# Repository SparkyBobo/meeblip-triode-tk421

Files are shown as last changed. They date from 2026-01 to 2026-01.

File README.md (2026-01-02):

# That Time I Promised My Friend a Synth… and Finally Delivered (40 Years Later!)

Let’s rewind to the 1980s—big hair, neon everything, and me, a seventh grader with a wild electronics obsession. Enter my buddy “F” (not his real name, but let’s roll with it—think F Murray Abraham from Amadeus,

because inside jokes are forever). F was the piano prodigy, I was the kid who thought soldering irons were cool, and together we were the ultimate middle school odd couple.

One day, I had a brilliant idea: “Hey F, why don’t you give me a few hundred bucks so I can build you a Moog-style synthesizer from a magazine article?” Because that’s how open-source worked back then—no GitHub, just guts and glue.

F, being the wise soul, realized this was probably a recipe for disaster (and possibly a fire hazard). Instead, F asked for a Roland synth for Christmas. Smart move, right? That was the moment F’s musical journey truly began.

He’s now a fantastic musician, and we rocked out in our high school band, the *Residudes*. F swears my synth hype is what nudged him from classical piano to modern music, so I’ll take partial credit for his rockstar status.

Fast forward: F and I still swap music nerd tidbits. He’s even inspired me to learn music (shoutout to my 70+ day Duolingo streak!). But here’s the kicker—I never actually built that synth. Oops. So, I decided it was time to

make good on my decades-old promise. After some deep dives into my parts bin and the wilds of the internet, I found the perfect open-source project: the [MeeBlip Triode](https://meeblip.com/products/meeblip-triode-synthesizer). It’s affordable, it’s awesome, and it’s my way of finally delivering on that synth promise from the Reagan era.

So here’s to friendship, music, and never letting a 40-year-old promise die. Sometimes, the best things really are worth the wait.

## Build Notes: AKA “How I Frankensteined This Synth Together”

* Parts Bin Olympics: My main goal was to spend as little money as possible on parts, not to be cheap, just to makes this a thing I threw together as much as possible.
* Analog Chip Hunt: Turns out, my stash didn’t have the right analog chips. Had to buy those. Same story for eight matching 10k potentiometers—those got ordered, but I did have a vintage audio taper 10k for volume just chilling in the bin.
* Processor Swap: The original build called for a different processor, but I had an ATMega 644 lying around, so why not? Plus, the DIP-40 package gives it that retro “I built this in the 80s” vibe. I tried to stick to the original circuit and microprocessor connections as much as possible not because I'm afraid of firmware changes, I just thoughts it would be easier.
* Through-Hole Throwback: Most resistors and capacitors are through-hole, because that’s what I had and they look delightfully vintage. Non-electrolytic caps? All from a random kit I bought for experimenting.
* Why use 1 part when 2 will do: Some components ended up with two passives in parallel or series. Why? Because I was determined to use what I had instead of buying new stuff. If you spot C14.1, C14.2, R15.1, or R15.2 looking a little extra, that’s just me flexing my parts bin muscles.
* Surface Mount Sneak-In: A few surface mount parts made it in, mostly to save space and because I had leftovers. Sorry for the modern touch, but hey, it’s all about balance.
* PCB Front Panel Hack: I love using PCBs as front panels—Kicad makes layout a breeze and it’s cheap. This synth is rocking three boards: bottom for the guts, middle for perfect potentiometer height, and the faceplate for that pro finish.
* Oldest Part Award: The power switch is a true relic—I’ve been lugging it around since the late 80s. It's actually an ON-OFF-ON switch but I thought when else am I gonna use it? And what's so bad about having 2 on positions? Runnerup is the resistors: Straight outta my college electronics kit from the late 80s/early 90s.

## Where Credit Is Due

Let’s be real: this project is standing on the shoulders of other. I didn’t just whip up the MeeBlip Triode out of thin air—there’s a whole crew who did the heavy lifting long before I ever busted out my soldering iron. So, here’s a big, sparkly shout-out (because it’s not just what the license says, it’s the right thing to do):

MeeBlip Contributors:

* Jarek Ziembicki: The OG—created the original AVRsynth, which is the backbone of this whole project.
* Laurie Biddulph: Translation superstar! Worked with Jarek to make those comments readable in English and ported the code to Atmega16.
* Daniel Kruszyna: Idea machine—extended AVRsynth and sprinkled in several concepts that MeeBlip now rocks.
* Julian Schmidt: Filter genius—came up with the original Meeblip digital filter algorithm.
* Axel Werner: Code ninja—optimized, squashed bugs, and brought in new bandlimited waveforms.
* James Grahame: Hardware and firmware mastermind behind MeeBlip’s physical and digital awesomeness.
* [MeeBlip Triode on GitHub](https://github.com/MeeBlip/meeblip-triode)

So, if you’re loving this synth saga, send some good vibes to these legends. Without their brainpower, my 40-year-old promise would still be stuck in the parts bin!

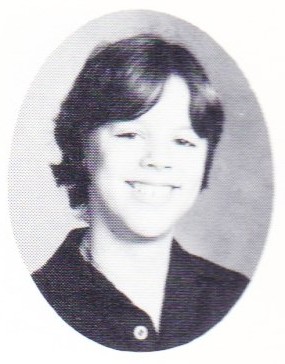
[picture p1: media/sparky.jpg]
Sparky from 1983
Sparky: 

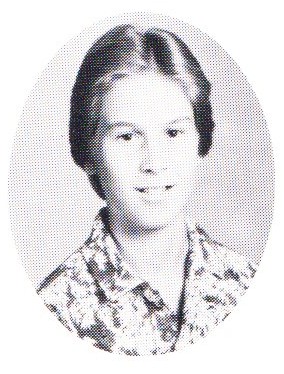
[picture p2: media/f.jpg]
F from 1983
F:

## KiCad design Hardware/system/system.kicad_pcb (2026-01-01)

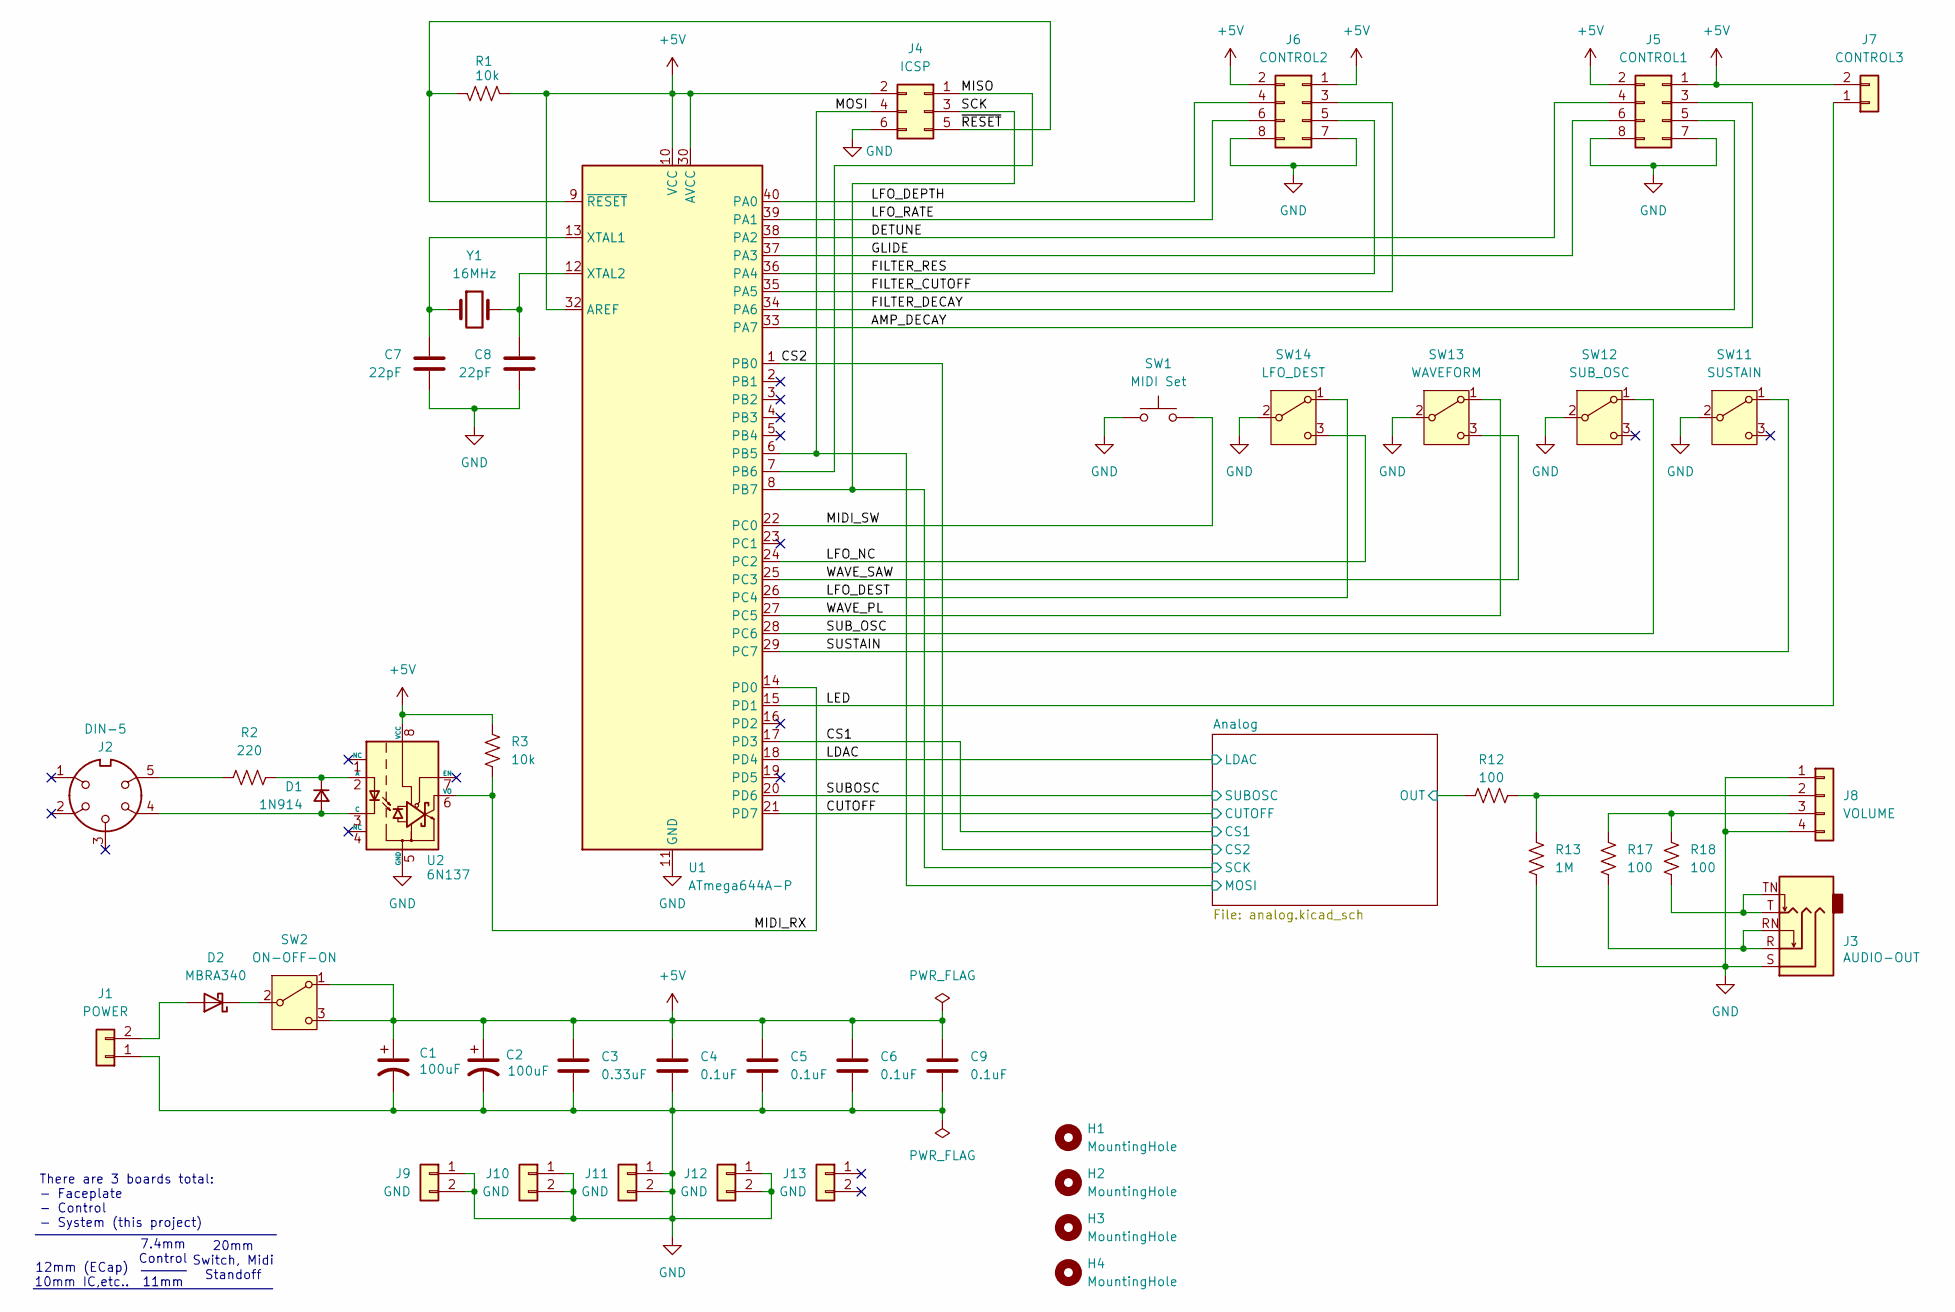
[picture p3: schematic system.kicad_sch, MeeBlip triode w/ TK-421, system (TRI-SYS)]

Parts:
C1, C2: 100uF; CP_Radial_D5.0mm_P2.00mm
C3: 0.33uF; C_Rect_L7.2mm_W3.0mm_P5.00mm_FKS2_FKP2_MKS2_MKP2
C4, C5, C6, C9: 0.1uF; C_Rect_L7.2mm_W3.0mm_P5.00mm_FKS2_FKP2_MKS2_MKP2
C7, C8: 22pF; C_Rect_L7.2mm_W3.0mm_P5.00mm_FKS2_FKP2_MKS2_MKP2
D1: 1N914; D_DO-35_SOD27_P10.16mm_Horizontal
D2: MBRA340; D_SMA_Handsoldering
H1, H2, H3, H4: MountingHole; MountingHole_3mm
J1: POWER; PhoenixContact_MC_1,5_2-G-3.81_1x02_P3.81mm_Horizontal
J2: DIN-5; MIDI_DIN_5
J3: AUDIO-OUT; Jack_3.5mm_Adafruit_1699_Horizontal
J4: ICSP; PinHeader_2x03_P2.54mm_Vertical
J5: CONTROL1; PinHeader_2x04_P2.54mm_Vertical
J6: CONTROL2; PinHeader_2x04_P2.54mm_Vertical
J7: CONTROL3; PinHeader_1x02_P2.54mm_Vertical
J8: VOLUME; PinHeader_1x04_P2.54mm_Vertical
J9, J10, J11, J12, J13: GND; PinHeader_1x02_P2.54mm_Vertical
R1: 10k; R_1206_3216Metric_Pad1.30x1.75mm_HandSolder
R2: 220; R_Axial_DIN0207_L6.3mm_D2.5mm_P10.16mm_Horizontal
R3: 10k; R_Axial_DIN0207_L6.3mm_D2.5mm_P10.16mm_Horizontal
R12, R17, R18: 100; R_Axial_DIN0207_L6.3mm_D2.5mm_P10.16mm_Horizontal
R13: 1M; R_Axial_DIN0207_L6.3mm_D2.5mm_P10.16mm_Horizontal
SW1: MIDI Set; SW_PUSH_6mm
SW2: ON-OFF-ON; ESWITCH_100_SPDT_M1_RA
SW11: SUSTAIN; ESWITCH_100_SPDT_M1
SW12: SUB_OSC; ESWITCH_100_SPDT_M1
SW13: WAVEFORM; ESWITCH_100_SPDT_M1
SW14: LFO_DEST; ESWITCH_100_SPDT_M1
U1: ATmega644A-P; DIP-40_W15.24mm
U2: 6N137; DIP-8_W7.62mm
Y1: 16MHz; Crystal_HC49-U_Vertical

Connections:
+5V: C1.1, C2.1, C3.1, C4.1, C5.1, C6.1, C9.1, J4.2, J5.1, J5.2, J6.1, J6.2, J7.2, R1.1, R3.1, SW2.1 (A), SW2.3 (C), U1.10 (VCC), U1.30 (AVCC), U1.32 (AREF), U2.8 (VCC); also elsewhere on the board
/AMP_DECAY: J5.3, U1.33 (PA7)
/Analog/OUT: R12.1; also elsewhere on the board
/CS1: U1.17 (PD3); also elsewhere on the board
/CS2: U1.1 (PB0); also elsewhere on the board
/CUTOFF: U1.21 (PD7); also elsewhere on the board
/DETUNE: J5.4, U1.38 (PA2)
/FILTER_CUTOFF: J6.3, U1.35 (PA5)
/FILTER_DECAY: J5.5, U1.34 (PA6)
/FILTER_RES: J6.5, U1.36 (PA4)
/GLIDE: J5.6, U1.37 (PA3)
/LDAC: U1.18 (PD4); also elsewhere on the board
/LED: J7.1, U1.15 (PD1)
/LFO_DEPTH: J6.4, U1.40 (PA0)
/LFO_DEST: SW14.1 (A), U1.26 (PC4)
/LFO_NC: SW14.3 (C), U1.24 (PC2)
/LFO_RATE: J6.6, U1.39 (PA1)
/MIDI_RX: R3.2, U1.14 (PD0), U2.6 (VO)
/MIDI_SW: SW1.2, U1.22 (PC0)
/MISO: J4.1, U1.7 (PB6)
/MOSI: J4.4, U1.6 (PB5); also elsewhere on the board
/SCK: J4.3, U1.8 (PB7); also elsewhere on the board
/SUBOSC: U1.20 (PD6); also elsewhere on the board
/SUB_OSC: SW12.1 (A), U1.28 (PC6)
/SUSTAIN: SW11.1 (A), U1.29 (PC7)
/WAVE_PL: SW13.1 (A), U1.27 (PC5)
/WAVE_SAW: SW13.3 (C), U1.25 (PC3)
/~RESET: J4.5, R1.2, U1.9 (~RESET)
GND: C1.2, C2.2, C3.2, C4.2, C5.2, C6.2, C7.2, C8.2, C9.2, J1.1, J3.S, J4.6, J5.7, J5.8, J6.7, J6.8, J8.1, J8.4, J9.1, J9.2, J10.1, J10.2, J11.1, J11.2, J12.1, J12.2, R13.2, SW1.1, SW11.2 (B), SW12.2 (B), SW13.2 (B), SW14.2 (B), U1.11 (GND), U1.31 (GND), U2.5 (GND); also elsewhere on the board
unnamed: D1.2 (A), J2.4, U2.3 (C)
unnamed: D1.1 (K), R2.2, U2.2 (A)
unnamed: D2.2 (A), J1.2
unnamed: D2.1 (K), SW2.2 (B)
unnamed: J2.5, R2.1
unnamed: J3.R, J3.RN, R17.2
unnamed: J3.T, J3.TN, R18.2
unnamed: J8.2, R12.2, R13.1
unnamed: J8.3, R17.1, R18.1
unnamed: C7.1, U1.13 (XTAL1), Y1.1
unnamed: C8.1, U1.12 (XTAL2), Y1.2

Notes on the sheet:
There are 3 boards total: - Faceplate - Control - System (this project)
10mm IC,etc..
20mm Switch, Midi Standoff
12mm (ECap)
11mm
7.4mm Control

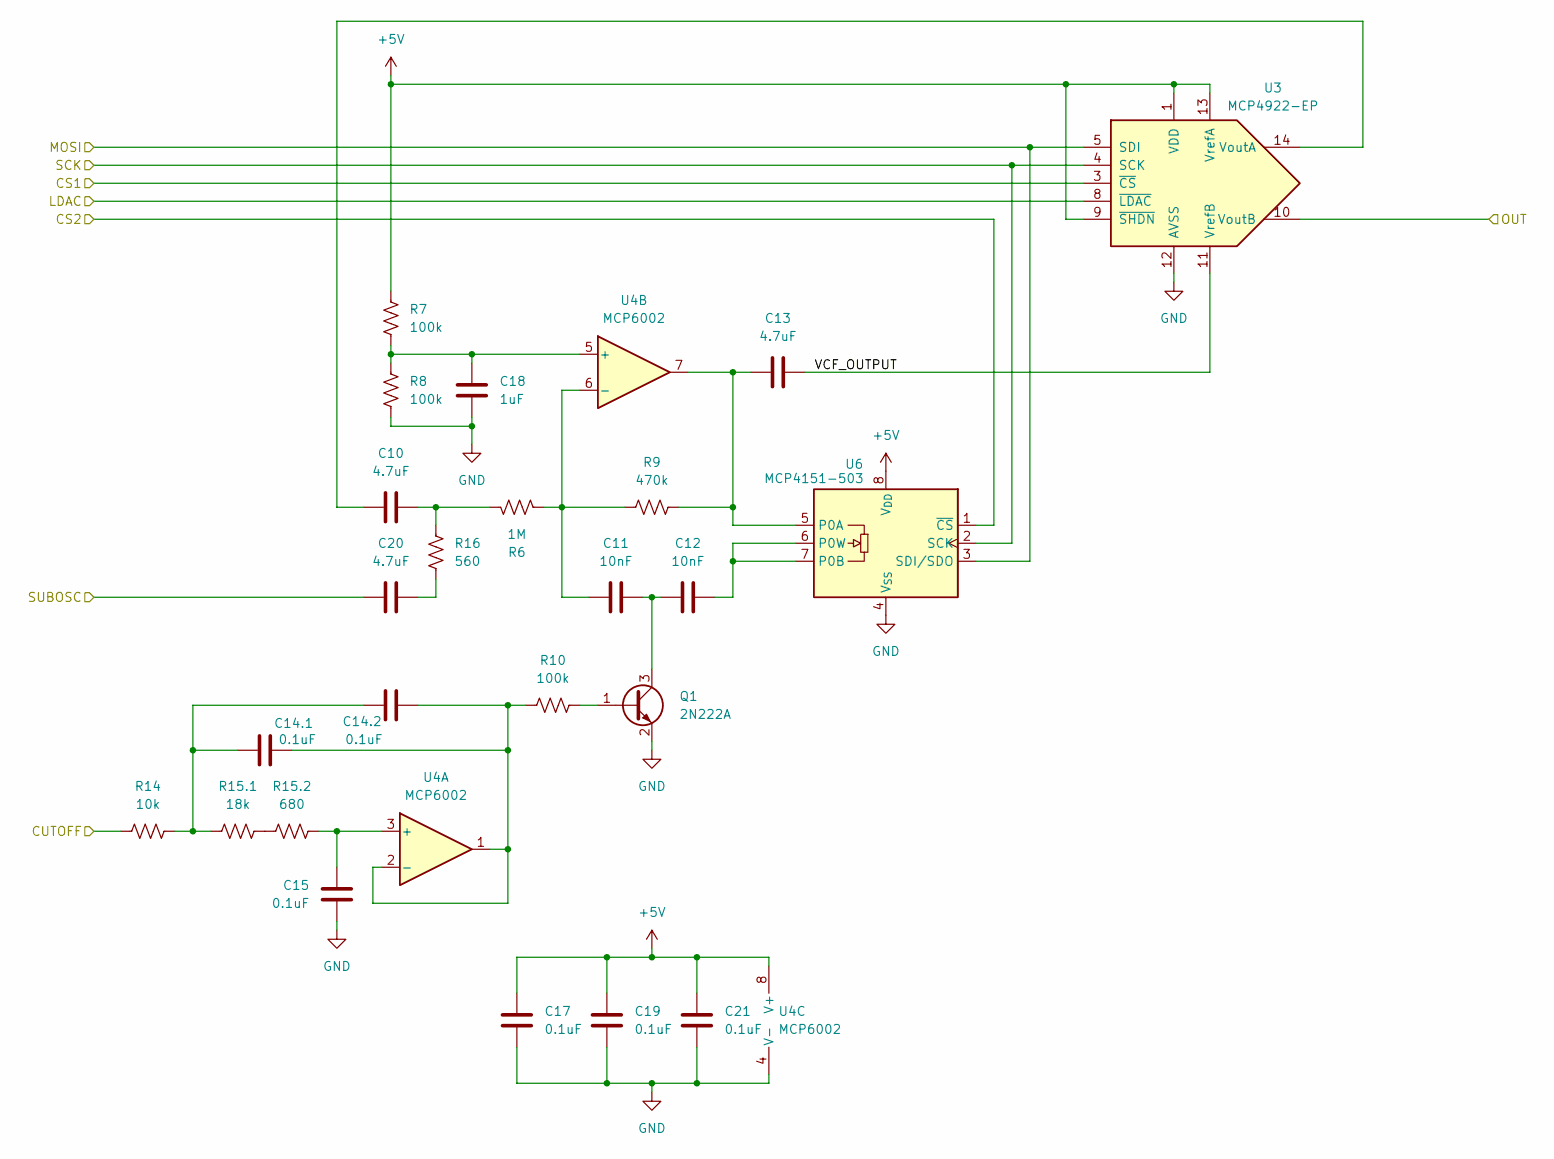
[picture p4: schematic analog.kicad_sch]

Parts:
C10, C13, C20: 4.7uF; C_Rect_L7.2mm_W3.0mm_P5.00mm_FKS2_FKP2_MKS2_MKP2
C11, C12: 10nF; C_Rect_L7.2mm_W3.0mm_P5.00mm_FKS2_FKP2_MKS2_MKP2
C14.1, C14.2, C15, C17, C19, C21: 0.1uF; C_Rect_L7.2mm_W3.0mm_P5.00mm_FKS2_FKP2_MKS2_MKP2
C18: 1uF; C_Rect_L7.2mm_W3.0mm_P5.00mm_FKS2_FKP2_MKS2_MKP2
Q1: 2N222A; TO-92_HandSolder
R6: 1M; R_Axial_DIN0207_L6.3mm_D2.5mm_P10.16mm_Horizontal
R7, R8, R10: 100k; R_Axial_DIN0207_L6.3mm_D2.5mm_P10.16mm_Horizontal
R9: 470k; R_Axial_DIN0207_L6.3mm_D2.5mm_P10.16mm_Horizontal
R14: 10k; R_Axial_DIN0207_L6.3mm_D2.5mm_P10.16mm_Horizontal
R15.1: 18k; R_Axial_DIN0207_L6.3mm_D2.5mm_P10.16mm_Horizontal
R15.2: 680; R_Axial_DIN0207_L6.3mm_D2.5mm_P10.16mm_Horizontal
R16: 560; R_Axial_DIN0207_L6.3mm_D2.5mm_P10.16mm_Horizontal
U3: MCP4922-EP; DIP-14_W7.62mm
U4: MCP6002; DIP-8_W7.62mm
U6: MCP4151-503; DIP-8_W7.62mm

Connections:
+5V: C17.1, C19.1, C21.1, R7.1, U3.1 (VDD), U3.9 (~SHDN), U3.13 (VrefA), U4.8 (V+), U6.8 (V_{DD}); also elsewhere on the board
/Analog/OUT: U3.10 (VoutB); also elsewhere on the board
/Analog/VCF_OUTPUT: C13.2, U3.11 (VrefB)
/CS1: U3.3 (~CS); also elsewhere on the board
/CS2: U6.1 (~CS); also elsewhere on the board
/CUTOFF: R14.1; also elsewhere on the board
/LDAC: U3.8 (~LDAC); also elsewhere on the board
/MOSI: U3.5 (SDI), U6.3 (SDI/SDO); also elsewhere on the board
/SCK: U3.4 (SCK), U6.2 (SCK); also elsewhere on the board
/SUBOSC: C20.1; also elsewhere on the board
GND: C15.2, C17.2, C18.2, C19.2, C21.2, Q1.2 (E), R8.2, U3.12 (AVSS), U4.4 (V-), U6.4 (V_{SS}); also elsewhere on the board
unnamed: C10.2, R6.2, R16.1
unnamed: C14.1.1, C14.2.2, R14.2, R15.1.1
unnamed: C20.2, R16.2
unnamed: Q1.1 (B), R10.2
unnamed: C11.2, C12.1, Q1.3 (C)
unnamed: R15.1.2, R15.2.1
unnamed: C10.1, U3.14 (VoutA)
unnamed: C15.1, R15.2.2, U4.3 (+)
unnamed: C14.1.2, C14.2.1, R10.1, U4.1, U4.2 (-)
unnamed: C18.1, R7.2, R8.1, U4.5 (+)
unnamed: C11.1, R6.1, R9.1, U4.6 (-)
unnamed: C13.1, R9.2, U4.7, U6.5 (P0A)
unnamed: C12.2, U6.6 (P0W), U6.7 (P0B)

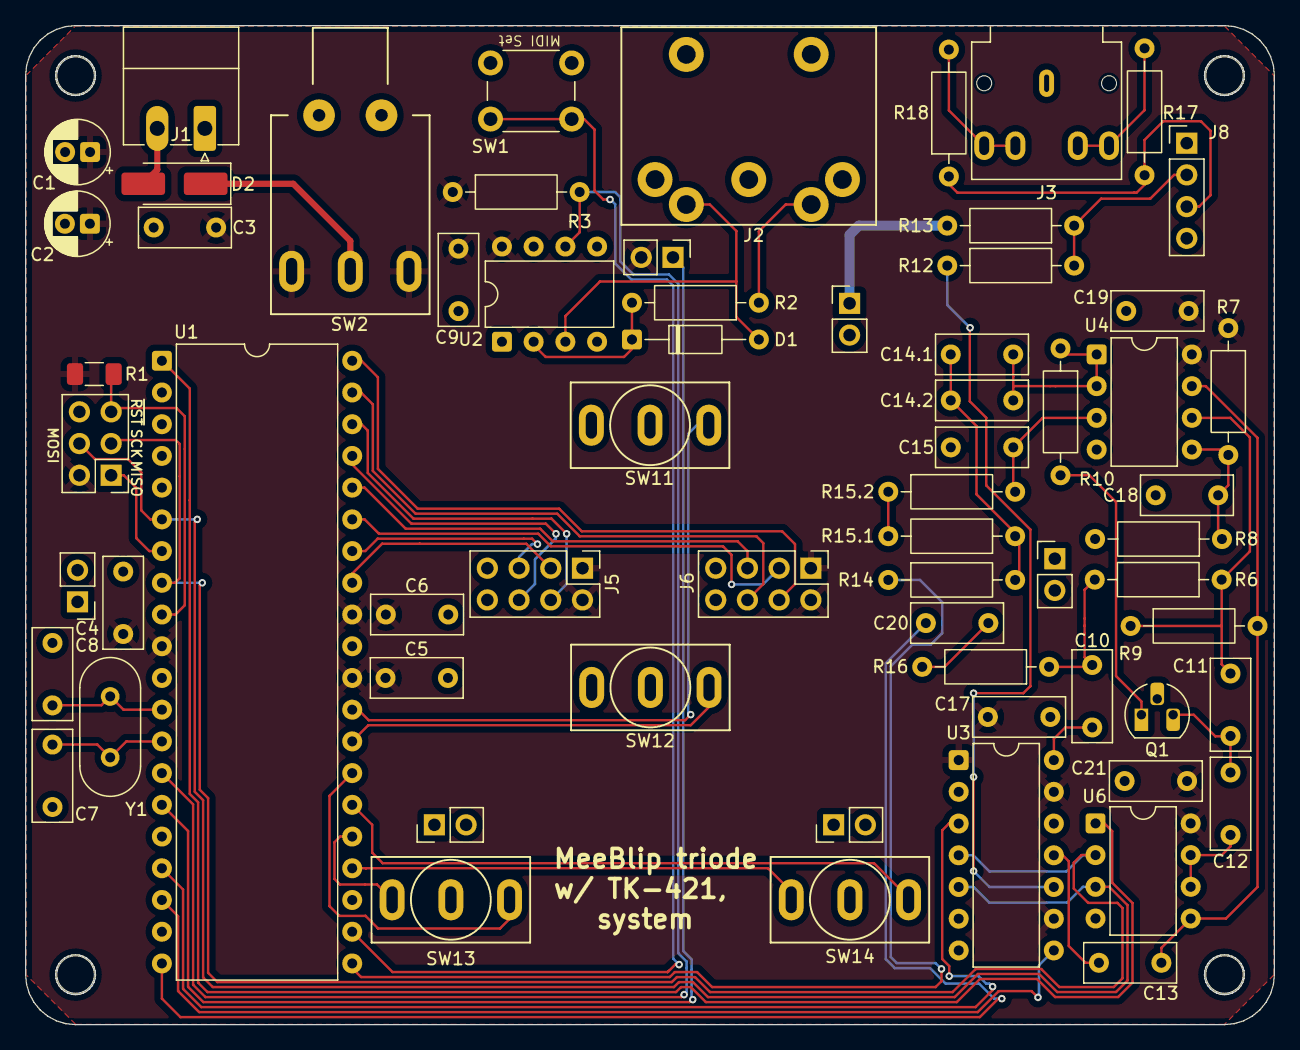
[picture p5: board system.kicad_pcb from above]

Board: 2 copper layers, 100.0 x 80.0 mm, 69 parts (0 on the bottom side), 54 nets.

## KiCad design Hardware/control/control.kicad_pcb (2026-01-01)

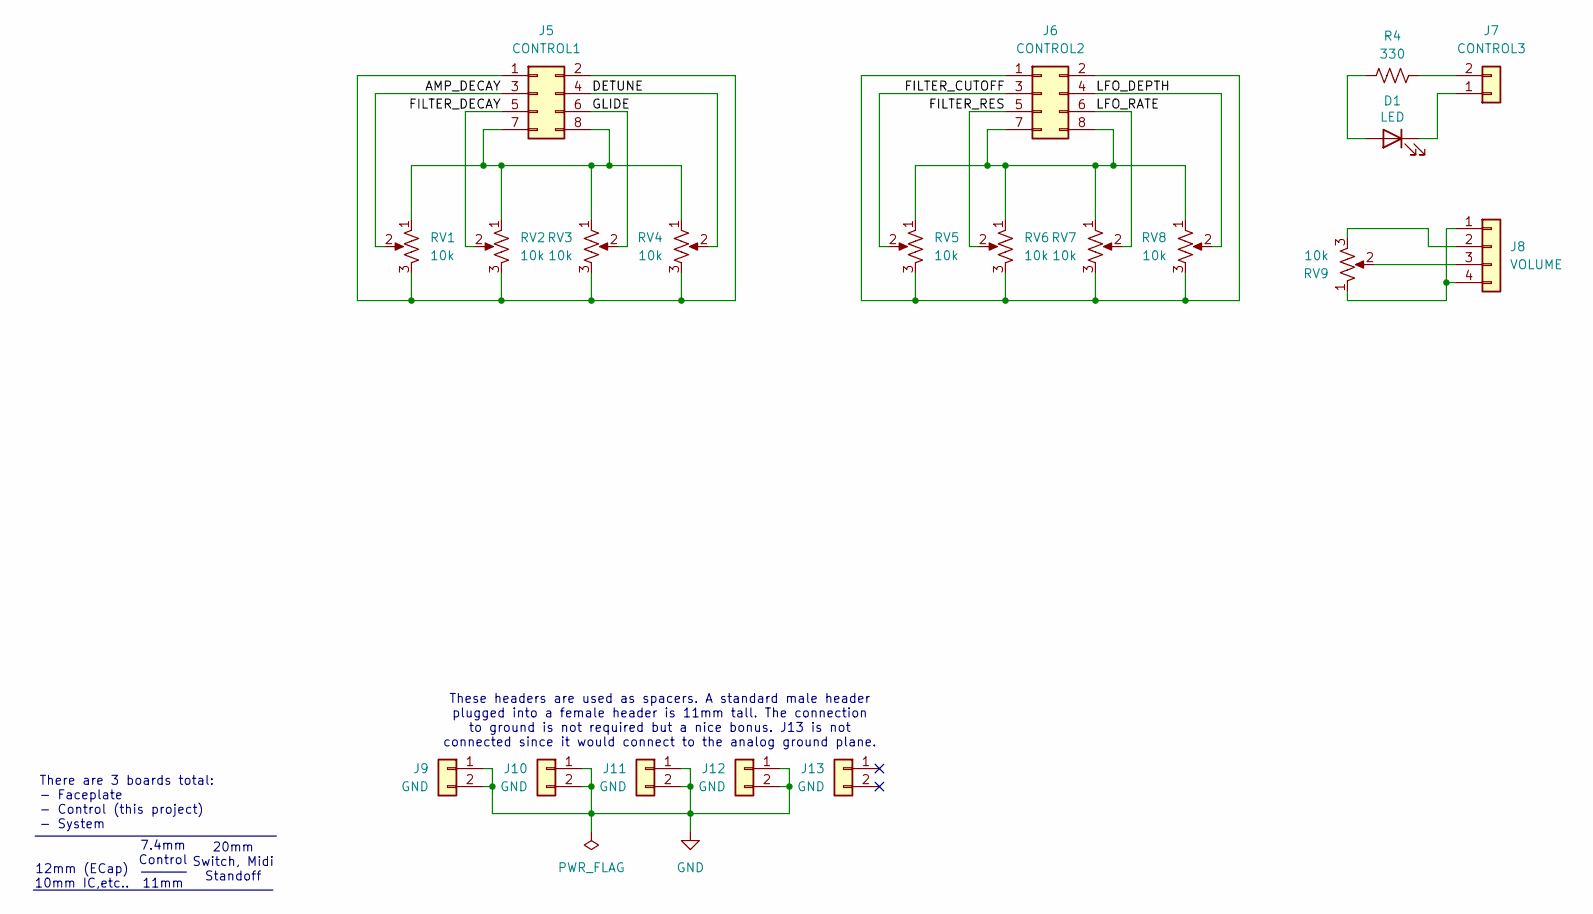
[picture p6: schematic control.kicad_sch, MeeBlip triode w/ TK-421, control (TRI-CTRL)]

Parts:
D1: LED; LED_D5.0mm
J5: CONTROL1; PinHeader_2x04_P2.54mm_Vertical
J6: CONTROL2; PinHeader_2x04_P2.54mm_Vertical
J7: CONTROL3; PinHeader_1x02_P2.54mm_Vertical
J8: VOLUME; PinHeader_1x04_P2.54mm_Vertical
J9, J10, J11, J12, J13: GND; PinHeader_1x02_P2.54mm_Vertical
R4: 330; R_Axial_DIN0207_L6.3mm_D2.5mm_P10.16mm_Horizontal
RV1, RV2, RV3, RV4, RV5, RV6, RV7, RV8, RV9: 10k; BOURNS_PTV09A_1

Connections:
/AMP_DECAY: J5.3, RV1.2
/DETUNE: J5.4, RV4.2
/FILTER_CUTOFF: J6.3, RV5.2
/FILTER_DECAY: J5.5, RV2.2
/FILTER_RES: J6.5, RV6.2
/GLIDE: J5.6, RV3.2
/LFO_DEPTH: J6.4, RV8.2
/LFO_RATE: J6.6, RV7.2
GND: J9.1, J9.2, J10.1, J10.2, J11.1, J11.2, J12.1, J12.2
unnamed: D1.2 (A), R4.1
unnamed: D1.1 (K), J7.1
unnamed: J5.1, J5.2, RV1.3, RV2.3, RV3.3, RV4.3
unnamed: J5.7, J5.8, RV1.1, RV2.1, RV3.1, RV4.1
unnamed: J6.1, J6.2, RV5.3, RV6.3, RV7.3, RV8.3
unnamed: J6.7, J6.8, RV5.1, RV6.1, RV7.1, RV8.1
unnamed: J7.2, R4.2
unnamed: J8.1, J8.4, RV9.1
unnamed: J8.2, RV9.3
unnamed: J8.3, RV9.2

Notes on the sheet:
11mm
20mm Switch, Midi Standoff
There are 3 boards total: - Faceplate - Control (this project) - System
12mm (ECap)
10mm IC,etc..
7.4mm Control
These headers are used as spacers. A standard male header plugged into a female header is 11mm tall. The connection to ground is not required but a nice bonus. J13 is not connected since it would connect to the analog ground plane.

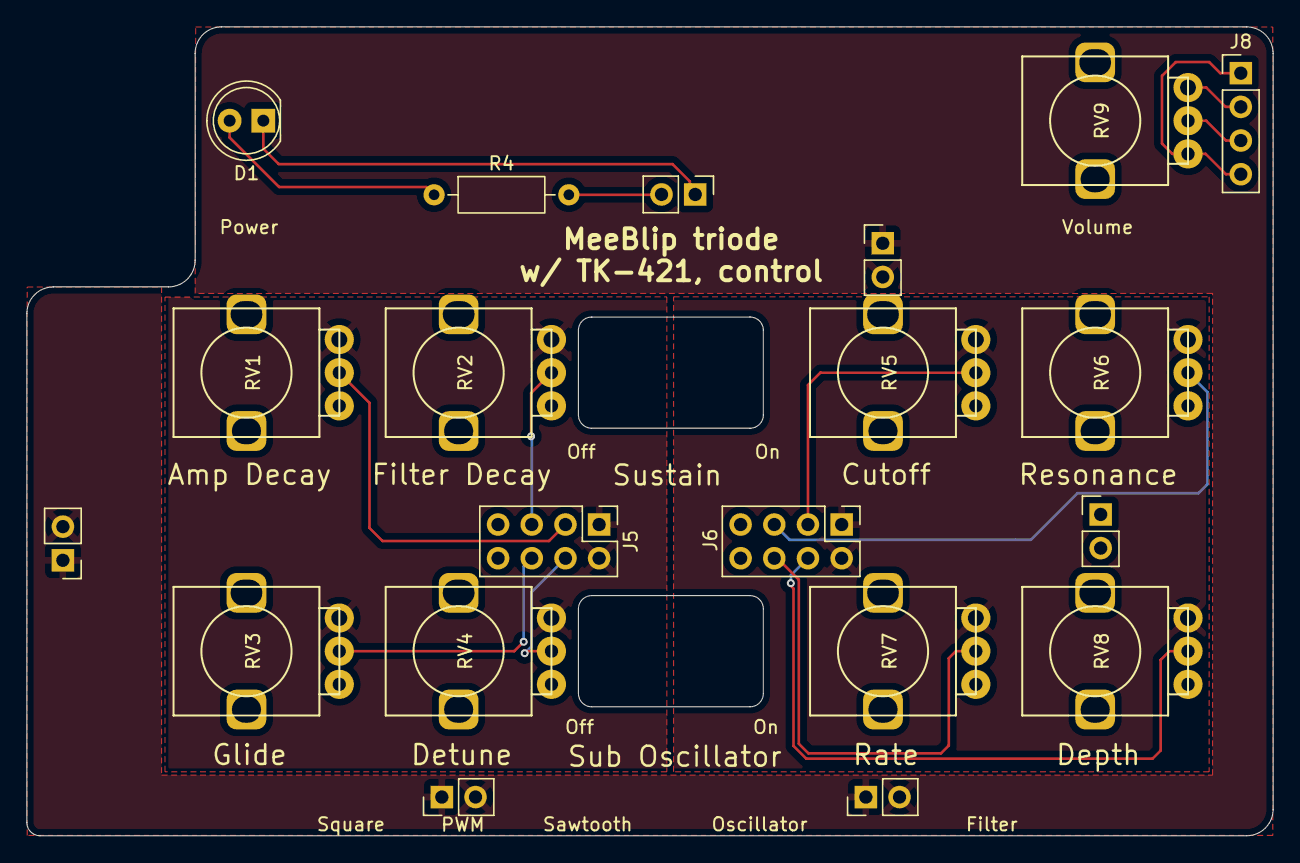
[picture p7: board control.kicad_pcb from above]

Board: 2 copper layers, 94.0 x 61.0 mm, 20 parts (0 on the bottom side), 19 nets.

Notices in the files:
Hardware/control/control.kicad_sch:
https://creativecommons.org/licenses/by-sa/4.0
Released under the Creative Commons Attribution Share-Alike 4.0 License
